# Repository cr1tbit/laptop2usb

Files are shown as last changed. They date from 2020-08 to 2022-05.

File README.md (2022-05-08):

# laptop2usb

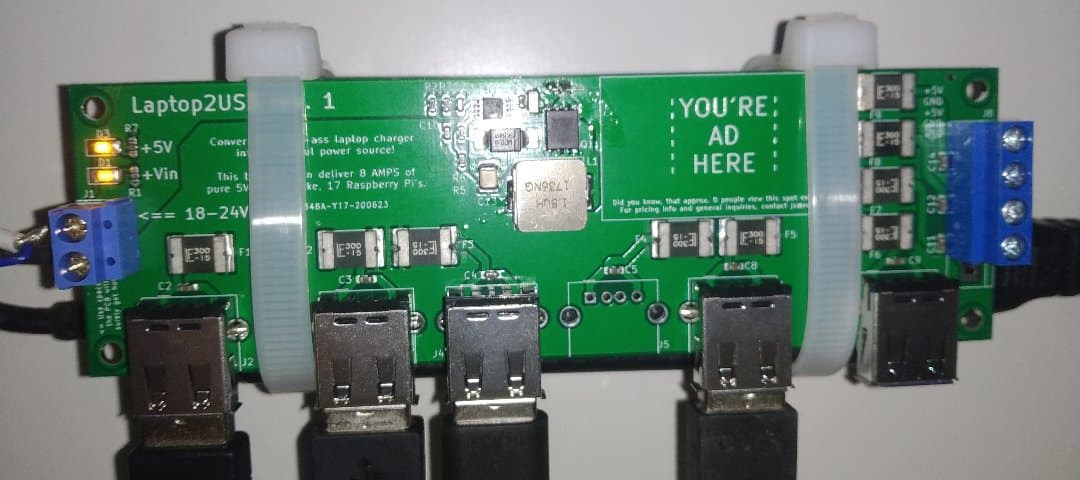
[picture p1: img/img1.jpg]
photo from top


### The premises
 
  * In tech-oriented public spaces there's constant shortage of wallplug USB chargers
  * The notebooks' powerbricks generally outlive the notebooks themself, so with enough effort you may get one for free
 
### How do I?

You fasten the PCB to a powerbrick.

The device takes anything between 17-20V, converts it into 5V, and splits into multiple USB and screw terminal ports. All of these ports are polyfuse-protected.

### Status

I'm yet to check a couple of things, and will do rev.2:
  * The converter gets super hot right now - is this OK? Calculate and document thermal resistance stuff. Verify converter efficiency.
  * Is the 10 mOhm current-limiting resistor even working?
  * The future is now - add USB C?
  * Maximum current it can handle (it was designed for 8A max, but I doubt it'll survive that for long)
  * Are USB ports wired properly? Do android/iOS/raspberry PIs utilize it well enough?
  * Now check the first letters of the list

### Trivia

I ordered the prototype from JLCPcb, with passive elements surface mounted. Their online tool automatically assigns the elements from BOM into the part numbers from their store. Apparently it parsed the shunt 10mOhm resistor as 10 Mega Ohms. 

With 10MegaOhms in the power path, the LM25085 somehow managed to produce 4V output with enough current to shine an onboard LED. Now that's dedication.

EDIT: it's been 2 years and one of my friends at work did literally the same kind of mistake when ordering PCBA from circuithub. I managed to catch that mistake quite fast, and implement a fix. I guess the lesson is, that those silly side-projects are really not in vain.

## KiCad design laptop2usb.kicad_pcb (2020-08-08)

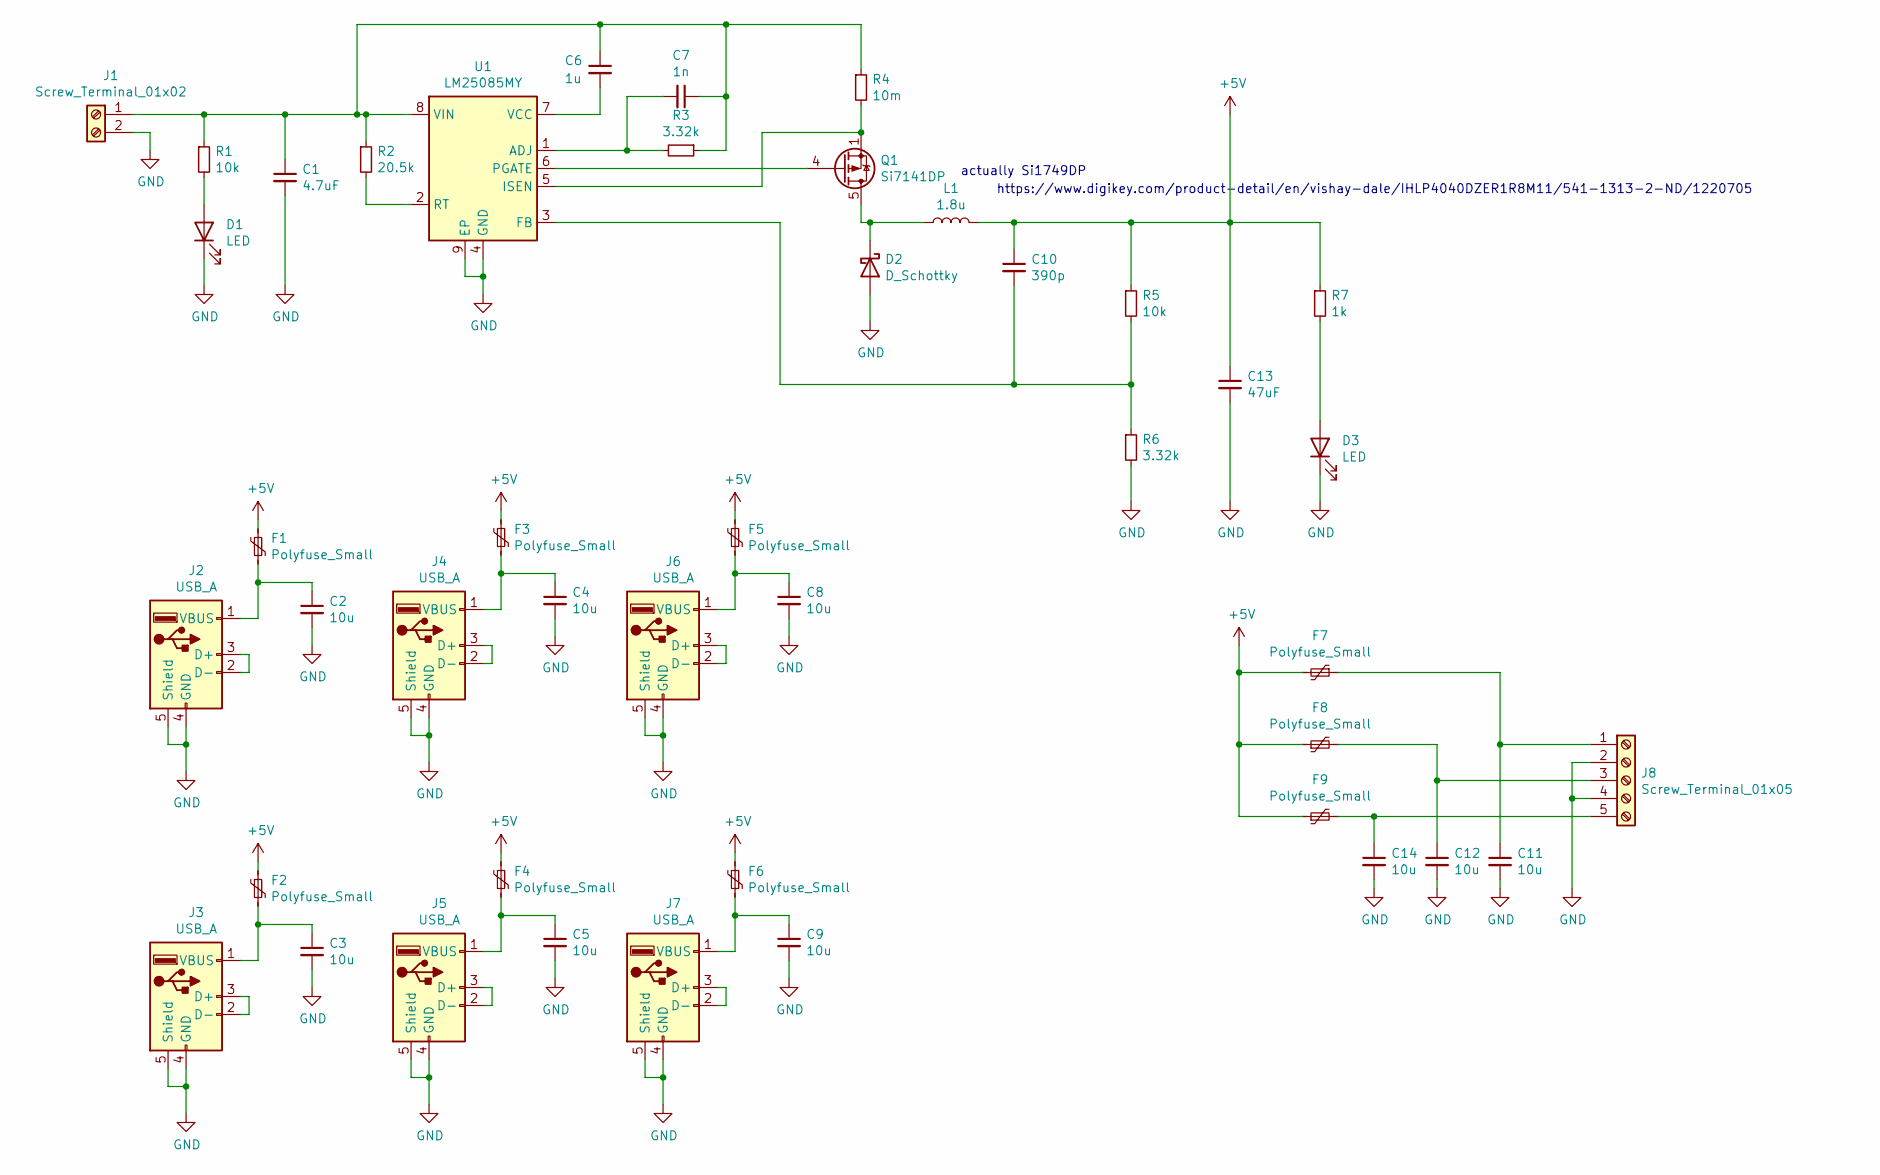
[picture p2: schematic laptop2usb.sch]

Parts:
C1: 4.7uF; C_0603_1608Metric_Pad1.05x0.95mm_HandSolder
C2, C3, C4, C5, C8, C9, C11, C12, C14: 10u; C_0603_1608Metric_Pad1.05x0.95mm_HandSolder
C6: 1u; C_0603_1608Metric_Pad1.05x0.95mm_HandSolder
C7: 1n; C_0603_1608Metric_Pad1.05x0.95mm_HandSolder
C10: 390p; C_0603_1608Metric_Pad1.05x0.95mm_HandSolder
C13: 47uF; C_1210_3225Metric_Pad1.42x2.65mm_HandSolder
D1, D3: LED; LED_1206_3216Metric_Pad1.42x1.75mm_HandSolder
D2: D_Schottky; D_SMB_Handsoldering
F1, F2, F3, F4, F5, F6, F7, F8, F9: Polyfuse_Small; Fuse_2920_7451Metric_Pad2.10x5.45mm_HandSolder
J1: Screw_Terminal_01x02; TerminalBlock_bornier-2_P5.08mm
J2, J3, J4, J5, J6, J7: USB_A; USB_A_Molex_67643_Horizontal
J8: Screw_Terminal_01x05; TerminalBlock_bornier-5_P5.08mm
L1: 1.8u; L_Vishay_IHLP-4040
Q1: Si7141DP; PowerPAK_SO-8_Single
R1, R5: 10k; R_0603_1608Metric_Pad1.05x0.95mm_HandSolder
R2: 20.5k; R_0603_1608Metric_Pad1.05x0.95mm_HandSolder
R3, R6: 3.32k; R_0603_1608Metric_Pad1.05x0.95mm_HandSolder
R4: 10m; R_0805_2012Metric_Pad1.15x1.40mm_HandSolder
R7: 1k; R_0603_1608Metric_Pad1.05x0.95mm_HandSolder
U1: LM25085MY; MSOP-8-1EP_3x3mm_P0.65mm_EP1.73x1.85mm_ThermalVias

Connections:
+5V: C10.1, C13.1, F1.1, F2.1, F3.1, F4.1, F5.1, F6.1, F7.2, F8.1, F9.1, L1.1, R5.1, R7.1
GND: C1.2, C2.2, C3.2, C4.2, C5.2, C8.2, C9.2, C11.2, C12.2, C13.2, C14.2, D1.1 (K), D2.2 (A), D3.1 (K), J1.2, J2.4 (GND), J2.5 (Shield), J3.4 (GND), J3.5 (Shield), J4.4 (GND), J4.5 (Shield), J5.4 (GND), J5.5 (Shield), J6.4 (GND), J6.5 (Shield), J7.4 (GND), J7.5 (Shield), J8.2, J8.4, R6.2, U1.4 (GND), U1.9 (EP)
unnamed: C1.1, C6.1, C7.1, J1.1, R1.1, R2.1, R3.1, R4.1, U1.8 (VIN)
unnamed: C2.1, F1.2, J2.1 (VBUS)
unnamed: C3.1, F2.2, J3.1 (VBUS)
unnamed: C4.1, F3.2, J4.1 (VBUS)
unnamed: C5.1, F4.2, J5.1 (VBUS)
unnamed: C6.2, U1.7 (VCC)
unnamed: C7.2, R3.2, U1.1 (ADJ)
unnamed: C8.1, F5.2, J6.1 (VBUS)
unnamed: C9.1, F6.2, J7.1 (VBUS)
unnamed: C10.2, R5.2, R6.1, U1.3 (FB)
unnamed: C11.1, F7.1, J8.1
unnamed: C12.1, F8.2, J8.3
unnamed: C14.1, F9.2, J8.5
unnamed: D1.2 (A), R1.2
unnamed: D2.1 (K), L1.2, Q1.5 (D)
unnamed: D3.2 (A), R7.2
unnamed: J2.2 (D-), J2.3 (D+)
unnamed: J3.2 (D-), J3.3 (D+)
unnamed: J4.2 (D-), J4.3 (D+)
unnamed: J5.2 (D-), J5.3 (D+)
unnamed: J6.2 (D-), J6.3 (D+)
unnamed: J7.2 (D-), J7.3 (D+)
unnamed: Q1.1 (S), Q1.2 (S), Q1.3 (S), R4.2, U1.5 (ISEN)
unnamed: Q1.4 (G), U1.6 (PGATE)
unnamed: R2.2, U1.2 (RT)

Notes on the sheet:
actually Si1749DP
https://www.digikey.com/product-detail/en/vishay-dale/IHLP4040DZER1R8M11/541-1313-2-ND/1220705

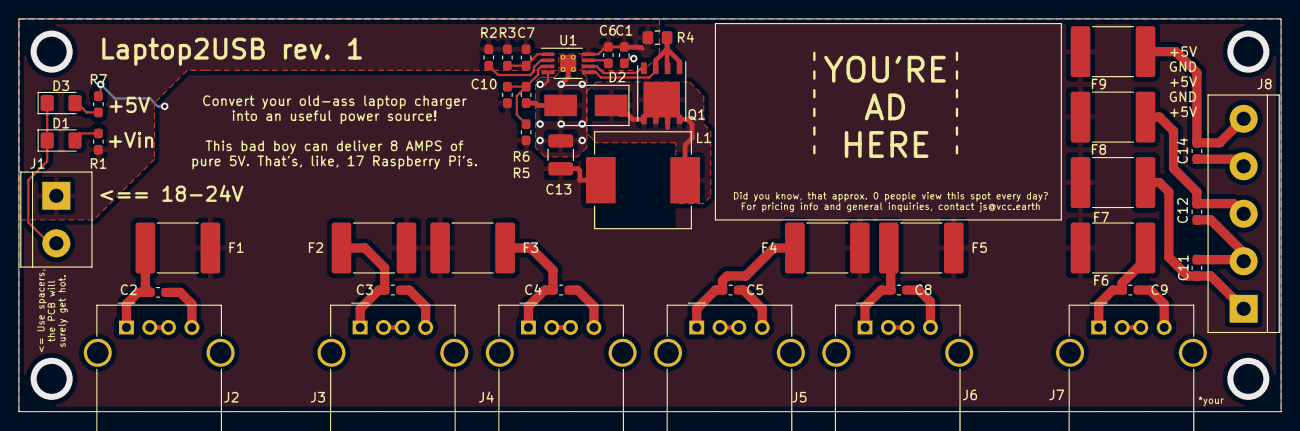
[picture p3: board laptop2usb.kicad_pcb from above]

Board: 2 copper layers, 135.0 x 42.0 mm, 44 parts (0 on the bottom side), 27 nets.
